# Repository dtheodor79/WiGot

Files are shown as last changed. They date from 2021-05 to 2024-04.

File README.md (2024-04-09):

# WiGot in a nutshell
WiGot is a quick effort for getting rid of all cables coming out from a Gotek drive installed in an Amiga. 
## Benefits
* No cables coming out of your Amiga
* Convenient image selection with rotary switch and OLED screen
 
 # Concept 
Up to know, most efforts focus on providing control panels with OLED screens, buttons / rotary switches, that are wired to the Gotek drive installed inside the Amiga. WiGot is a quick (and dirty) effort for getting rid of all cables coming out from a Gotek drive installed in an Amiga. It is based on connecting a small microcontoller with wireless connectivity capabilities inside the Gotek drive that emulates image selection from a rotary switch. An external wireless controller with OLED screen and a rotary switch, transmits user rotations to the internal microcontroller, which relays them to the Gotek processor.  
 
 # Prototype
 The current prototype is based on a SFRC9220 Gotek drive and two WeMos D1 EPS32 modules; the first one (A) is mounted inside a Gotek drive with HXC firmware, and the second one (B) allows users to select disk images. Communication works as follows: whenever the user rotates the switch, B informs A (including direction). A then simply uses the original Gotek rotary pins (that are already available) to emulate a full rotary (i.e. no grey encoding up to now). All data transfers are done using the [ESP Now](https://docs.espressif.com/projects/esp-idf/en/latest/esp32/api-reference/network/esp_now.html) wireless protocol.
 
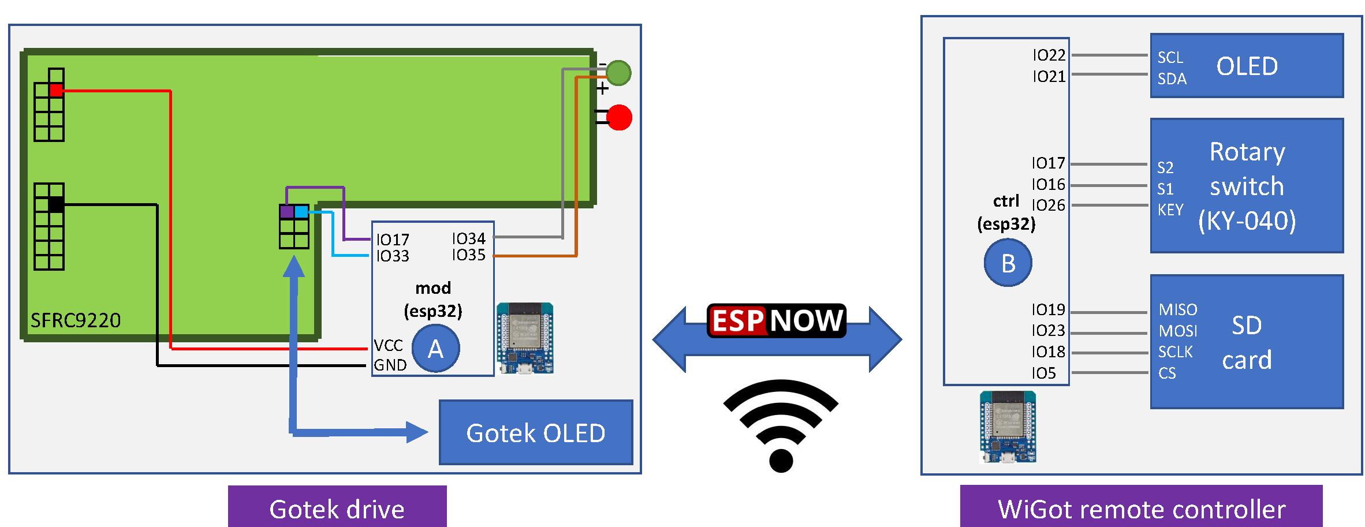
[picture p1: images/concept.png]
Concept


The image above illustates the WiGot concept, based on the two aforementioned WeMos D1 ESP32 modules, namely A and B. 

The left part shows how to connect A with the Gotek drive: 

* IO pins 17 and 33 are used to send fake rotary signals to the Gotek processor. 
* IO pins 34 and 35 are used to analog-read the voltage between the green led (L4 in the schematic), in order to identify whether the floopy is busy.
* VCC and GND pins are connected to the Gotek headers shown with red and black boxes.

The right parts shows how to build B:
* IO pins 22 and 21 are used for the I2C protocol required by the OLED.
* IO pins 17, 16 and 26 are connected to the S2, S1 and KEY pins respectevily of the KY-040 rotary switch.
* IO pins 19, 23, 18 and 5 are used for the SPI protocol required by the SD Card.

# How to use it
## First-time use
After you connect A to the Gotek drive as shown above, follow these steps:
### Create and save the data file
* Create a data.cfg file and edit it as follows:
    * the first line must contain the MAC address of A, seperated by commas. [Here](https://randomnerdtutorials.com/get-change-esp32-esp8266-mac-address-arduino/) you can see how to read the ESP MAC address. Example for MAC address B4:E6:2D:8F:D8:E1 in the data file:
        * B4,E6,2D,8F,D8,E1 
    * each subsequent line must contain a single image's data in the form of &lt;name&gt;,&lt;disk&gt;,&lt;total disks&gt;. Example with HXC firmware and Desert Strike images: 
        * HXCFECFGV1.0,1,1
        * Desert Strike,1,3
        * Desert Strike,2,3
        * Desert Strike,3,3
* Save the data file into your FAT32 formatted SD card.
* Plug the SD card into the slot of the controller module (B).
* An example of my data.cfg file can be found here.
### Power up
Now that you have created your data.cfg file and saved it in the SD card, follow these steps:
* Power up your Amiga, A will wait for B.
* Plug B to power, and check the OLED screen; it will take a while to establish connection with A and then ask you to set the current image.
* Rotate the switch until the image number matches the one shown in the Gotek OLED screen. When done, press the rotary switch once to sync the controller with the image selected in the Gotek drive.
* That's it! From now can use the rotary switch to select images.
## Regular use
Always power on first the Amiga and then directly the wireless controller B. Wait for a moment to establish connection and then start selecting images. In case you add / remove images, you need to update the data.cfg file as well, using the instructions above.

# FAQ - Troubleshoot
* Image number does not match the one shown in the Gotek drive OLED screen
  * If, for any reason, this happens, simply press the rotary switch to set again the currently selected image from the Gotek drive. Note that A and B should be already connected before syncing the image.
* Cannot establish connection between A and B
  * Make sure that the MAC address is correct and properly saved (each number separated by commas) in the first line of the data.cfg file.
* The rotary switch does not work properly
  * The WiGot current implementation assumes the following S1 and S2 (of the KY-040) states:
    * Single clockwise rotation (increases selected image by 1): 10 → 00 → 01 → 11 → 10
    * Single counter-clockwise rotation (decreases selected image by 1): 00 → 10 → 11 → 01 → 00  
 
# WiGot images

## Mod (A)

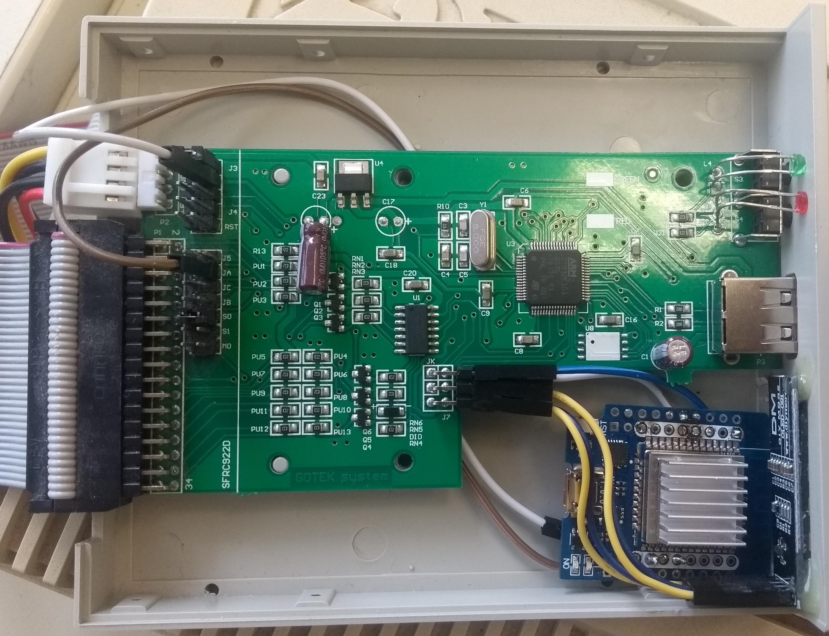
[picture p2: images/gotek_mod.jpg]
Gotek mod


## Wireless controller (B)

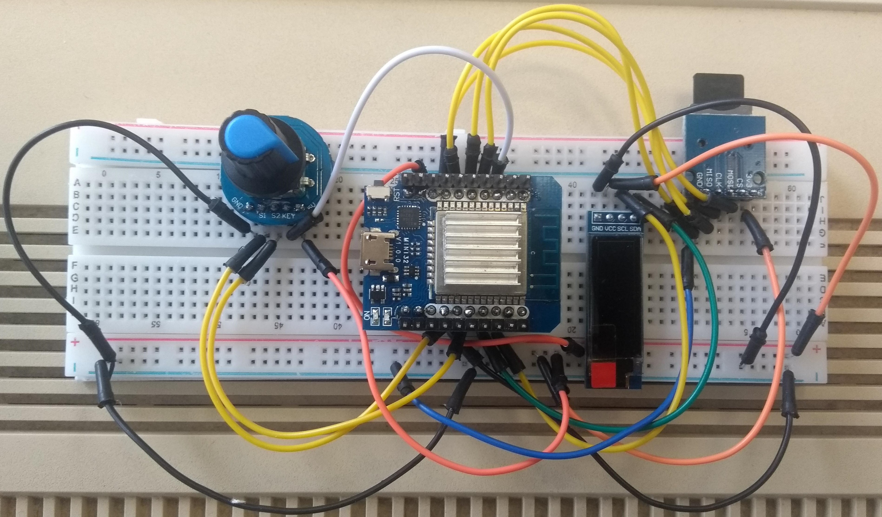
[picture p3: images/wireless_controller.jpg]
Wireless controller


Here you can find a clumsy PCB made with KiCAD for the wireless controller.

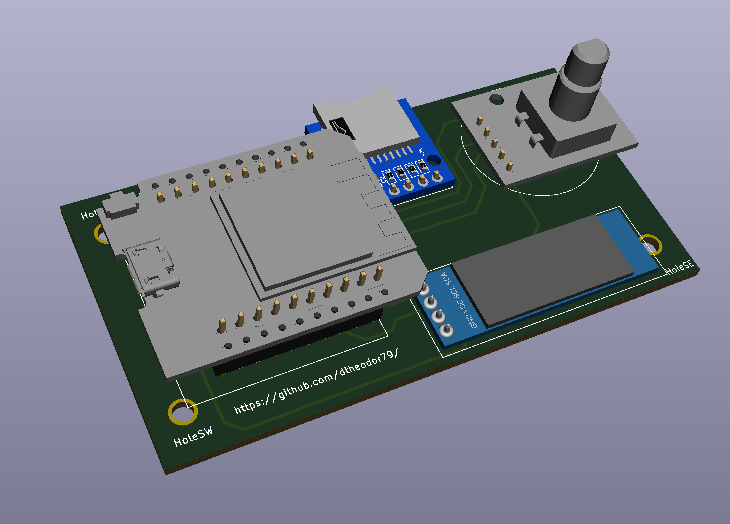
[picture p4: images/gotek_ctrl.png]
Model


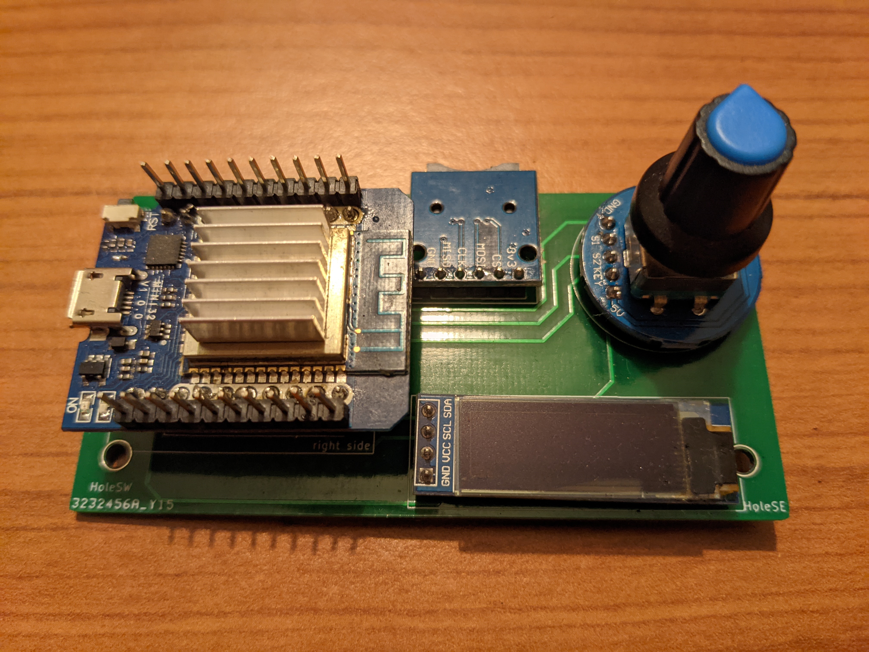
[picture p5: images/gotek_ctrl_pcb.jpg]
Controller_Pcb


Hope you find it useful!! :sunglasses:

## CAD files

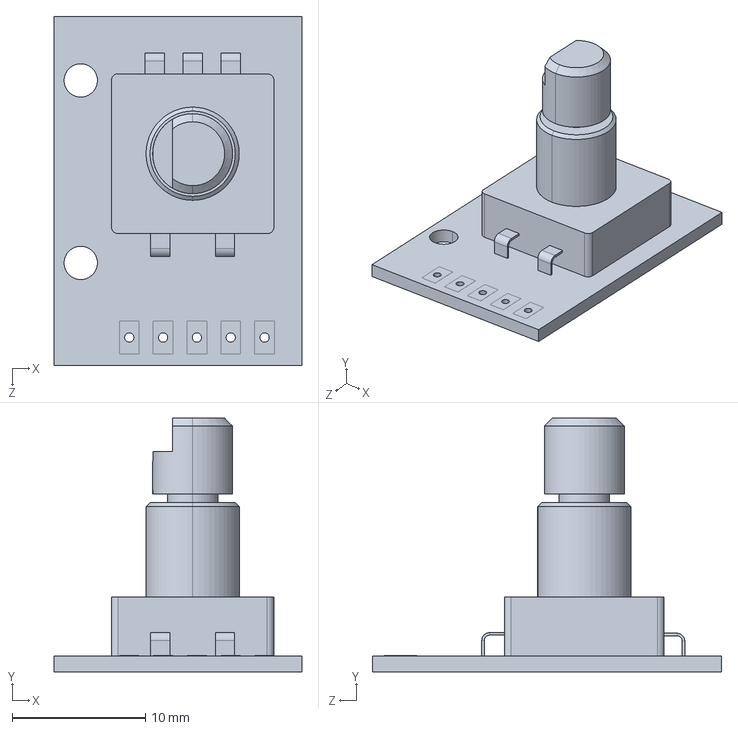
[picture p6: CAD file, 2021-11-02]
gotek_ctrl/pcb/3d models/Encoder KY-040.STEP
18.6 x 19.1 x 26.2 mm

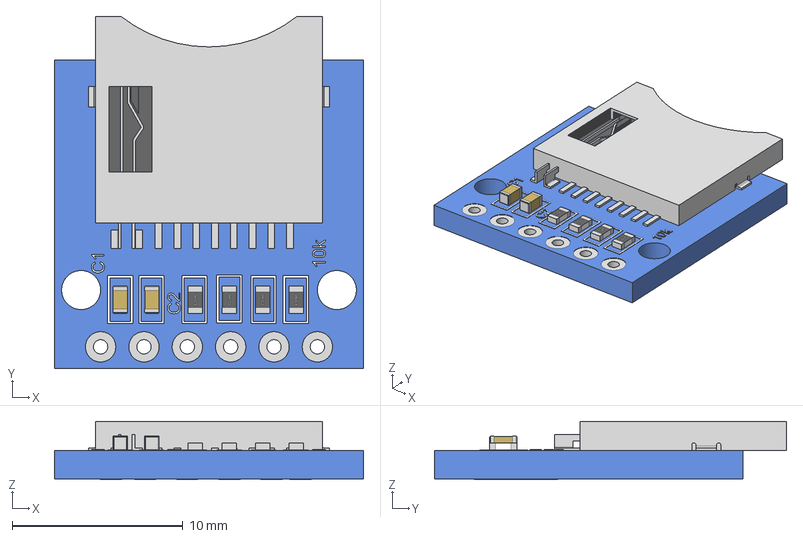
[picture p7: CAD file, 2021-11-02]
gotek_ctrl/pcb/3d models/MicroSD Card Module - 1.stp
18.1 x 20.6 x 3.40 mm
Micro SD Module - 1
MicroSD
0603 Capacitor x 2
0603 Resistor x 4

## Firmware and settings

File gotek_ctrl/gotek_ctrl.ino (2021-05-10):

#include <HardwareSerial.h>
#include <Wire.h>
#include <Adafruit_SSD1306.h>
#include <esp_now.h>
#include <WiFi.h>
#include "SD.h"
#include "SPI.h"
#include "FS.h"
#include <EEPROM.h>

#define SERIAL_UART_BAUD   57600 
#define LED_PIN       GPIO_NUM_2 
#define I2C_SDA       GPIO_NUM_21
#define I2C_SCL       GPIO_NUM_22
#define KY040_S2      GPIO_NUM_17
#define KY040_S1      GPIO_NUM_16
#define KY040_BUTTON  GPIO_NUM_26
#define INC10_BUTTON  GPIO_NUM_35  //TODO
#define DEC10_BUTTON  GPIO_NUM_33  //TODO
#define SCREEN_WIDTH 128 // OLED display width, in pixels
#define SCREEN_HEIGHT 32 // OLED display height, in pixels    
#define DISPLAY_I2C_ADDRESS 0x3C 

#define ROTARY_ENC_OUT_A  GPIO_NUM_19
#define ROTARY_ENC_OUT_B  GPIO_NUM_18

#define SD_MISO     GPIO_NUM_19
#define SD_MOSI     GPIO_NUM_23
#define SD_SCLK     GPIO_NUM_18
#define SD_CS       GPIO_NUM_5

#define OLED_TIMEOUT_MSEC 21000 
#define RX_DATA_START -9    
#define OLED_STATUS_REQUEST -6
#define OLED_STATUS_UNKNOWN -8
#define OLED_ON -7    
#define OLED_OFF -5
#define CONNECTION_TEST -2
#define ROTARY_DELAY_USEC 100000
#define ROTARY_OUTPUTS_DELAY 10
#define MIN_BUTTON_PRESSES_INTERVAL_MSEC 300
#define SWITCH_ROTATION_CCW -3
#define SWITCH_ROTATION_CW -4
#define MOD_PROBE_SUCCESS 0
#define MOD_PROBE_UNKNOWN -1
#define MOD_PROBE_FAIL 1
#define IMAGE_DATA_NUM 1024

uint32_t rotatorPressedTimestamp = 0;

typedef struct {
  char imageName[64];
  char currentDiskNum;  
  char totalDisksNum;  
} imageEntryData;

imageEntryData imageData[IMAGE_DATA_NUM];

bool aState = LOW, bState = LOW, settingGotekImage = false, dataFileFound = false, initProcessSuccess = false;
int8_t counter = 0, rotatorPressedCounter = 0, modProbeResult = MOD_PROBE_UNKNOWN;
bool oledAvailable = false, clearOledDisplay = false;

const int imageSettingIdx_eepromAdress = 0;
Adafruit_SSD1306 display(SCREEN_WIDTH, SCREEN_HEIGHT, &Wire, -1);
static uint8_t prevNextCode = 0;
static uint16_t store = 0;
static int16_t imageSettingIdx = -1, totalAvailableImages = 0, initOledStatus = OLED_STATUS_UNKNOWN;
uint32_t selectionSleepTimeMsec = OLED_TIMEOUT_MSEC;

//gotek_ctrl mac is CC:50:E3:B5:9E:38
//gotek_mod mac is CC:50:E3:B5:A1:1C
uint8_t gotekCtrlAddress[6];
//uint8_t gotekModAddress[] = {0xCC, 0x50, 0xE3, 0xB5, 0xA1, 0x1C};
uint8_t gotekModAddress[6]; //read from the SD card
portMUX_TYPE mux = portMUX_INITIALIZER_UNLOCKED;

void saveInt16ToEEPROM (int eepromAddress,int16_t value) {  
  EEPROM.put(eepromAddress, value);    
  EEPROM.commit();
}

int16_t loadInt16FromEEPROM(int eepromAddress) {
  int16_t readData;
  EEPROM.get(eepromAddress, readData);
  return readData;
}

void clearEEPROM() {
  Serial.print("clear EEPROM ");
  for (int i = 0; i < 512; i++) {
    EEPROM.write(i, -1);
  }
  EEPROM.commit();
  delay(500);
  Serial.println("done!");
}

//callback function that will be executed when data is received
void OnDataRecv(const uint8_t * mac, const uint8_t *incomingData, int len) {  
  int16_t dataReceived = 0;
  
  memcpy(&dataReceived, incomingData, sizeof(int16_t));
  Serial.print("Bytes received: ");
  Serial.println(len);  
  Serial.println("dataReceived = " + String(dataReceived)); 
  if (dataReceived >= 0) {
    imageSettingIdx = dataReceived;
    Serial.println("imageSettingIdx = " + String(imageSettingIdx)); 
    saveInt16ToEEPROM(imageSettingIdx_eepromAdress,imageSettingIdx);   
  }  
  else {
    if (dataReceived == (int16_t)OLED_OFF) {
      clearOledDisplay = true;
      initOledStatus = (int16_t)OLED_OFF;
    }
    else if (dataReceived == (int16_t)OLED_ON) {
      clearOledDisplay = false;
      initOledStatus = (int16_t)OLED_ON;
    }
  }  
}

// callback when data is sent
void OnDataSent(const uint8_t *mac_addr, esp_now_send_status_t status) {
  char macStr[18];
  Serial.print("Packet to: ");
  // Copies the sender mac address to a string
  snprintf(macStr, sizeof(macStr), "%02x:%02x:%02x:%02x:%02x:%02x",mac_addr[0], mac_addr[1], mac_addr[2], mac_addr[3], mac_addr[4], mac_addr[5]);
  Serial.print(macStr);
  Serial.print(" send status:\t");
  Serial.println(status == ESP_NOW_SEND_SUCCESS ? "Delivery Success" : "Delivery Fail");
  (status == ESP_NOW_SEND_SUCCESS) ? modProbeResult = MOD_PROBE_SUCCESS : modProbeResult = MOD_PROBE_FAIL;  
}

void rotatorPressedRoutine() {
  rotatorPressedCounter++;
  rotatorPressedTimestamp = millis();
  Serial.println("rotatorPressedRoutine, rotatorPressedCounter = " + String(rotatorPressedCounter) + ", settingGotekImage = " + String(settingGotekImage));  
  if (settingGotekImage) {
    if (imageSettingIdx >= 0) {
      settingGotekImage = false;
      sendDataToMod(imageSettingIdx);    
      writeToDisplay("Image set!");    
      delay(1000);
      showImageDataToDisplay();
    }
  }
  else {    
    setGotekImage();  
  }  
}

// A vald CW or  CCW move returns 1, invalid returns 0.
//credits for the debouncing function here: https://www.best-microcontroller-projects.com/rotary-encoder.html
int8_t readRotary() {
  static int8_t rotEncTable[] = {0,1,1,0,1,0,0,1,1,0,0,1,0,1,1,0};

  prevNextCode <<= 2;
  if (digitalRead(KY040_S1)) prevNextCode |= 0x02;
  if (digitalRead(KY040_S2)) prevNextCode |= 0x01;
  prevNextCode &= 0x0f;

  // If valid then store as 16 bit data.
  if  (rotEncTable[prevNextCode] ) {
    store <<= 4;
    store |= prevNextCode;      
    if ((store&0xff)==0x2b) return -1;
    if ((store&0xff)==0x17) return 1;
  }
  return 0;
}

void sendDataToMod(int16_t dataToSend) {
  esp_err_t result = esp_now_send(0, (uint8_t *) &dataToSend, sizeof(int16_t));  
}

void detectRotation() {  
  int8_t val;  bool cw = false;   

  if (val=readRotary()) {    
    cw = (val == 1);

    if (settingGotekImage) {
      imageSettingIdx +=val;      
      if (imageSettingIdx < 0) {
        imageSettingIdx = totalAvailableImages-1;  
      }
      if (imageSettingIdx > totalAvailableImages-1) {
        imageSettingIdx = 0; 
      }
      Serial.println("detectRotation , imageSettingIdx = " + String(imageSettingIdx));
      saveInt16ToEEPROM(imageSettingIdx_eepromAdress,imageSettingIdx);
    }
    setRotaryEncOutputsGotekStates(cw); 
  }  
}

void setRotaryEncOutputA(bool newState) {
  digitalWrite(ROTARY_ENC_OUT_A, newState);
  aState = newState;
}

void setRotaryEncOutputB(bool newState) {
  digitalWrite(ROTARY_ENC_OUT_B, newState);
  bState = newState;
}


void setRotaryEncOutputsGotekStates(bool cw) {
  Serial.println("setRotaryEncOutputsGotekStates, cw = " + String(cw));  
  if (cw) {
    //CW: 10 > 00 > 01 > 11 > 10
    setRotaryEncOutputA(HIGH); setRotaryEncOutputB(LOW);
    Serial.print(String(aState) + String(bState) + " -> ");     
    delay(ROTARY_OUTPUTS_DELAY); 
    setRotaryEncOutputA(LOW); setRotaryEncOutputB(LOW);
    Serial.print(String(aState) + String(bState) + " -> ");  
    delay(ROTARY_OUTPUTS_DELAY);
    setRotaryEncOutputA(LOW); setRotaryEncOutputB(HIGH);
    Serial.print(String(aState) + String(bState) + " -> ");    
    delay(ROTARY_OUTPUTS_DELAY);
    setRotaryEncOutputA(HIGH); setRotaryEncOutputB(HIGH);
    Serial.print(String(aState) + String(bState) + " -> ");   
    delay(ROTARY_OUTPUTS_DELAY);
    setRotaryEncOutputA(HIGH); setRotaryEncOutputB(LOW);
    Serial.println(String(aState) + String(bState));      
    delay(ROTARY_OUTPUTS_DELAY);
  }
  else {
    //CCW: 00 > 10 > 11 > 01 > 00
    setRotaryEncOutputA(LOW); setRotaryEncOutputB(LOW);
    Serial.print(String(aState) + String(bState) + " -> ");  
    delay(ROTARY_OUTPUTS_DELAY); 
    setRotaryEncOutputA(HIGH); setRotaryEncOutputB(LOW);
    Serial.print(String(aState) + String(bState) + " -> ");
    delay(ROTARY_OUTPUTS_DELAY);
    setRotaryEncOutputA(HIGH); setRotaryEncOutputB(HIGH);
    Serial.print(String(aState) + String(bState) + " -> ");
    delay(ROTARY_OUTPUTS_DELAY);
    setRotaryEncOutputA(LOW); setRotaryEncOutputB(HIGH);
    Serial.print(String(aState) + String(bState) + " -> ");
    delay(ROTARY_OUTPUTS_DELAY);
    setRotaryEncOutputA(LOW); setRotaryEncOutputB(LOW);
    Serial.println(String(aState) + String(bState));      
    delay(ROTARY_OUTPUTS_DELAY);
  }  

  showImageDataToDisplay();
  
  if (!settingGotekImage) {    
    int16_t cwRotation = (cw == true) ? SWITCH_ROTATION_CW : SWITCH_ROTATION_CCW;
    //esp_err_t result = esp_now_send(0, (uint8_t *) &cwRotation, sizeof(uint8_t));  
    sendDataToMod(cwRotation);
  }
}

void showImageDataToDisplay() {
  Serial.println("imageSettingIdx = " + String(imageSettingIdx));
  if ((imageSettingIdx >=0) && (imageSettingIdx < IMAGE_DATA_NUM)) {
    String textToDisplay = String("Image ") + String(imageSettingIdx) + String( " / ") + String(totalAvailableImages-1) + String("\n\n") + String(imageData[imageSettingIdx].imageName) + String("\nDisk ") + String(imageData[imageSettingIdx].currentDiskNum) + String(" / ") + String(imageData[imageSettingIdx].totalDisksNum);
    writeToDisplay(textToDisplay);  
  }
  else {  //ask the user to set the currently selected image in Gotek
    setGotekImage();
  }
}

void setGotekImage(){
  settingGotekImage = true;    
  writeToDisplay("Set active image.");
}

void writeToDisplay(String text) {
  if (oledAvailable) {    
    Serial.println("writeToDisplay: text = " + text);      
    display.clearDisplay();
    display.setCursor(0, 0);  
    display.println(text);
    display.display(); 

    digitalWrite(LED_PIN,text.length() > 0);
  }  
}

void readDataFile(File imagesFile) {
  Serial.println("readDataFile...");      
  char buffer[64]; 
  int i=0;
  while (imagesFile.available()) {
    int l = imagesFile.readBytesUntil('\n', buffer, sizeof(buffer));
    buffer[l] = 0;

    char* imageMetaData = strtok(buffer, ","); 
    if (i==0) {  //contains the mod MAC address      
      sscanf(imageMetaData,"%02x",&gotekModAddress[0]);                       
      imageMetaData = strtok(NULL, ","); sscanf(imageMetaData,"%02x",&gotekModAddress[1]);  
      imageMetaData = strtok(NULL, ","); sscanf(imageMetaData,"%02x",&gotekModAddress[2]);  
      imageMetaData = strtok(NULL, ","); sscanf(imageMetaData,"%02x",&gotekModAddress[3]);  
      imageMetaData = strtok(NULL, ","); sscanf(imageMetaData,"%02x",&gotekModAddress[4]);  
      imageMetaData = strtok(NULL, ","); sscanf(imageMetaData,"%02x",&gotekModAddress[5]);  
      
      Serial.print("mod MAC address: ");
      for (int j=0;j<5;j++) {
        Serial.print(String(gotekModAddress[j],HEX) + ":");
      }
      Serial.println(String(gotekModAddress[5],HEX));
    }
    else {
      strcpy(&(imageData[i-1].imageName[0]),imageMetaData);
      imageMetaData = strtok(NULL, ","); 
      strcpy(&(imageData[i-1].currentDiskNum),imageMetaData);
      imageMetaData = strtok(NULL, ","); 
      strcpy(&(imageData[i-1].totalDisksNum),imageMetaData);
    }      
    i++;     
  }
  totalAvailableImages = i-1;
  Serial.println("totalAvailableImages = " + String(totalAvailableImages));
  printImageNames(); 
}

void printImageNames() {  
  for (int i=0;i<totalAvailableImages;i++) {    
    Serial.println("imageName: " + String(imageData[i].imageName) + ", currentDiskNum: " + String(imageData[i].currentDiskNum) + ", totalDisksNum: " + String(imageData[i].totalDisksNum));
  }
}


bool initializeOLED() {
  byte errorResult;
  Wire.beginTransmission(DISPLAY_I2C_ADDRESS);
  errorResult = Wire.endTransmission(); 

  if (errorResult == 0) {
    if (!display.begin(SSD1306_SWITCHCAPVCC, DISPLAY_I2C_ADDRESS)) { // Address 0x3C for 128x32
      Serial.println("SSD1306 allocation failed"); 
      return false;   
    }
    else {
      Serial.println("SSD1306 allocation successful!");    
      // Clear the buffer
      display.clearDisplay();
      display.setTextSize(1); // Draw 2X-scale text
      display.setTextColor(SSD1306_WHITE);    
    }
    return true;
  }

  Serial.println("SSD1306 not available!");    
  return false;
}

void checkIfRotatorPressed() {
  if (digitalRead(KY040_BUTTON) == LOW) {
    if (rotatorPressedTimestamp == 0) {
      rotatorPressedRoutine();    
    }
    else {    
      if (millis() - rotatorPressedTimestamp > MIN_BUTTON_PRESSES_INTERVAL_MSEC) {
        rotatorPressedRoutine();
      }
    }
  }  
}

bool sendInitDataToMod() {
  uint8_t maxTries = 20, progress = 0, progressStep = 12;
  
  Serial.println("sendInitDataToMod..");

  WiFi.macAddress(gotekCtrlAddress);
  for (int i=0;i<6;i++) {
    Serial.println("gotekCtrlAddress[" + String(i) + "] = " + String(gotekCtrlAddress[i],HEX));    
  } 
  
  do {
    delay(1000);
    sendDataToMod((int16_t)RX_DATA_START);
    if (modProbeResult != MOD_PROBE_SUCCESS) {
      maxTries--;      
    }    
  }
  while ((modProbeResult != MOD_PROBE_SUCCESS) && (maxTries >= 0));
  progress = progress + progressStep;
  writeToDisplay("Connecting to mod...\n" + String(progress) + "%");

  for (int i=0;i<6;i++) {
    do {
    delay(1000);
      sendDataToMod((int16_t)gotekCtrlAddress[i]);  
      if (modProbeResult != MOD_PROBE_SUCCESS) {
        maxTries--;      
      } 
    }
    while ((modProbeResult != MOD_PROBE_SUCCESS) && (maxTries >= 0));
    progress = progress + progressStep;
    writeToDisplay("Connecting to mod...\n" + String(progress) + "%");
  }

  do {
    delay(1000);
    sendDataToMod((int16_t)totalAvailableImages);
    if (modProbeResult != MOD_PROBE_SUCCESS) {
      maxTries--;      
    }    
  }
  while ((modProbeResult != MOD_PROBE_SUCCESS) && (maxTries >= 0));

  Serial.println("sendInitDataToMod, maxTries = " + String(maxTries));
  if (maxTries >=0) {
    writeToDisplay("Connecting to mod...\ndone!");
    return true;
  }

  writeToDisplay("Connecting to mod...\nerror :(");
  return false;
   
}


void setup() {
  int i=0;
  Serial.begin(SERIAL_UART_BAUD);
  delay(1000);  
  Serial.println("Starting gotek ctrl..."); 
  Wire.begin();  
  delay(1000);  
  WiFi.mode(WIFI_STA);  
  delay(1000);  
  Serial.println("MAC address: " + WiFi.macAddress());  

  EEPROM.begin(512);  
  //clearEEPROM(); 

  imageSettingIdx = loadInt16FromEEPROM(imageSettingIdx_eepromAdress); 
  Serial.println("imageSettingIdx = " + String(imageSettingIdx));

  pinMode(KY040_S2, INPUT);  
  pinMode(KY040_S2, INPUT_PULLUP);  
  pinMode(KY040_S1, INPUT);  
  pinMode(KY040_S1, INPUT_PULLUP);
  pinMode(KY040_BUTTON, INPUT); 

  pinMode(ROTARY_ENC_OUT_A, OUTPUT);
  setRotaryEncOutputA(LOW);
  pinMode(ROTARY_ENC_OUT_B, OUTPUT);
  setRotaryEncOutputB(LOW);
  pinMode(LED_PIN, OUTPUT);

  oledAvailable = initializeOLED();  
  writeToDisplay("Initializing...");  
  
  if (!SD.begin(SD_CS)){
    Serial.println("Card Mount Failed.");
    writeToDisplay("Card Mount Failed.");    
    return;
  }
  uint8_t cardType = SD.cardType();

  if (cardType == CARD_NONE){
    Serial.println("No SD card attached.");
    writeToDisplay("No SD card attached.");
    return;
  }

  Serial.print("SD Card Type: ");
  if (cardType == CARD_MMC){
    Serial.println("MMC");
  } 
  else if (cardType == CARD_SD){
    Serial.println("SDSC");
  } 
  else if (cardType == CARD_SDHC){
    Serial.println("SDHC");
  } 
  else {
    Serial.println("UNKNOWN");
  }

  uint64_t cardSize = SD.cardSize() / (1024 * 1024);
  Serial.printf("SD Card Size: %lluMB\n", cardSize);
  
  
  File imagesFile = SD.open("/data.cfg"); 
  if (!imagesFile){
    Serial.println("There was an error opening imagesFile");  
    writeToDisplay("\"data.cfg\" file not\nfound!"); 
    dataFileFound = false; 
    return;
  }
  else {
    Serial.println("imagesFile size = " + String(imagesFile.size()) + " bytes"); 
    dataFileFound = true;
    readDataFile(imagesFile);   
  }
  imagesFile.close();

  if (esp_now_init() != ESP_OK) {
    Serial.println("Error initializing ESP-NOW");
    writeToDisplay("Error connecting with Gotek.");
    return;
  }
  else {
    Serial.println("ESP-NOW initialized!");
  }
  
  esp_now_register_send_cb(OnDataSent);
  esp_now_register_recv_cb(OnDataRecv);
  // register gotekMod
  esp_now_peer_info_t gotekModInfo;
  gotekModInfo.channel = 0;  
  gotekModInfo.encrypt = false;
  // register first peer  
  memcpy(gotekModInfo.peer_addr, gotekModAddress, 6);
  if (esp_now_add_peer(&gotekModInfo) != ESP_OK){
    Serial.println("Failed to add peer");
    return;
  }
  else {
    Serial.println("Successfully added Gotek mod!");
    writeToDisplay("Connecting to mod...");
  }

  do {
    sendDataToMod((int16_t)CONNECTION_TEST);
    Serial.println("modProbeResult = " + String(modProbeResult));
    delay(1000);  
  }
  while (modProbeResult != MOD_PROBE_SUCCESS); 

  if (!dataFileFound) {
    writeToDisplay("\"data.cfg\" file not\nfound!"); 
    delay(1000);
  }

  //send initial data to mod
  initProcessSuccess = sendInitDataToMod();
  
  
}

void loop() {
  static bool connectionSuccess = true; 
  static int16_t prevImageSettingIdx = -1; 

  if (!initProcessSuccess) {
    return;
  }

  if (modProbeResult == MOD_PROBE_SUCCESS) {
    if (!connectionSuccess) {
      connectionSuccess = true;    
      showImageDataToDisplay();             
    }
    detectRotation();
    checkIfRotatorPressed(); 
    if (prevImageSettingIdx != imageSettingIdx) {
      showImageDataToDisplay(); 
      prevImageSettingIdx = imageSettingIdx;
    }      

    if (clearOledDisplay) {
      writeToDisplay("");
      clearOledDisplay = false;
    }
    
  }
  else {
    connectionSuccess = false;
    writeToDisplay("Not connected to mod!");
    sendDataToMod((int16_t)CONNECTION_TEST);
    delay(1000);
  }  
}

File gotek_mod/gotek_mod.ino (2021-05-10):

#include <HardwareSerial.h>
#include "WiFi.h"
#include <esp_now.h>
#include "driver/rtc_io.h"
#include <EEPROM.h>

#define SERIAL_UART_BAUD   57600  

#define RX_DATA_START -9    
#define OLED_STATUS_REQUEST -6
#define OLED_STATUS_UNKNOWN -8
#define OLED_ON -7    
#define OLED_OFF -5
#define SWITCH_ROTATION_CCW -3
#define SWITCH_ROTATION_CW -4
#define CONNECTION_TEST -2
#define CTRL_PROBE_SUCCESS 0
#define CTRL_PROBE_UNKNOWN -1
#define CTRL_PROBE_FAIL 1

#define LED_PIN GPIO_NUM_2
#define ROTARY_ENC_OUT_A  GPIO_NUM_33 
#define ROTARY_ENC_OUT_B  GPIO_NUM_17 
#define FLOPPY_LED_PLUS   GPIO_NUM_35
#define FLOPPY_LED_MINUS    GPIO_NUM_34
#define FLOPPY_READ_THRESHOLD 4000      
#define OLED_TIMEOUT_MSEC 21000     
#define IMAGE_DATA_NUM 1024

#define ROTARY_OUTPUTS_DELAY 10
#define TIMEOUT_TIMER_ID 0

//gotek_ctrl mac is CC:50:E3:B5:9E:38
//gotek_mod mac is CC:50:E3:B5:A1:1C
//uint8_t gotekCtrlAddress[] = {0xCC, 0x50, 0xE3, 0xB5, 0x9E, 0x38};
uint8_t gotekCtrlAddress[6];
hw_timer_t * timeOutTimer = NULL;
portMUX_TYPE timerMux = portMUX_INITIALIZER_UNLOCKED;
bool aState = LOW, bState = LOW, oledIsOn = true, prevOledIsOn = false,  floppyBusy = false, receivingInitDataFromCtrl = false;
uint32_t oledTimeOutMsec = OLED_TIMEOUT_MSEC, countDownTimerMsec = OLED_TIMEOUT_MSEC;
int16_t imageIdx = -1, totalAvailableImages = 0;
int8_t ctrlProbeResult = CTRL_PROBE_UNKNOWN, macRxIdx = 0;
const int imageIdx_eepromAdress = 0;

void saveInt16ToEEPROM (int eepromAddress,int16_t value) {  
  EEPROM.put(eepromAddress, value);    
  EEPROM.commit();
}

int16_t loadInt16FromEEPROM(int eepromAddress) {
  int16_t readData;
  EEPROM.get(eepromAddress, readData);
  return readData;
}

void clearEEPROM() {
  Serial.print("clear EEPROM ");
  for (int i = 0; i < 512; i++) {
    EEPROM.write(i, -1);
  }
  EEPROM.commit();
  delay(500);
  Serial.println("done!");
}

// callback when data is sent
void OnDataSent(const uint8_t *mac_addr, esp_now_send_status_t status) {
  char macStr[18];
  Serial.print("Packet to: ");
  // Copies the sender mac address to a string
  snprintf(macStr, sizeof(macStr), "%02x:%02x:%02x:%02x:%02x:%02x",mac_addr[0], mac_addr[1], mac_addr[2], mac_addr[3], mac_addr[4], mac_addr[5]);
  Serial.print(macStr);
  Serial.print(" send status:\t");
  Serial.println(status == ESP_NOW_SEND_SUCCESS ? "Delivery Success" : "Delivery Fail");
  (status == ESP_NOW_SEND_SUCCESS) ? ctrlProbeResult = CTRL_PROBE_SUCCESS : ctrlProbeResult = CTRL_PROBE_FAIL;  
}

//callback function that will be executed when data is received
void OnDataRecv(const uint8_t * mac, const uint8_t *incomingData, int len) {
  int16_t dataReceived = SWITCH_ROTATION_CCW;
  memcpy(&dataReceived, incomingData, sizeof(int16_t));
  Serial.print("Bytes received: ");
  Serial.println(len);  

  if (receivingInitDataFromCtrl) {
    if ((macRxIdx >= 0) && (macRxIdx <=5)) {
      Serial.println("dataReceived = 0x" + String(dataReceived,HEX));
      gotekCtrlAddress[macRxIdx] = (uint8_t)dataReceived;
    }
    else if (macRxIdx == 6) {
      Serial.println("dataReceived = " + String(dataReceived));
      totalAvailableImages = dataReceived;
      receivingInitDataFromCtrl = false;       
    }    
    macRxIdx++;
  }
  else {      
    Serial.println("dataReceived = " + String(dataReceived));
    if (dataReceived != CONNECTION_TEST) { //ignore connection test message
      if (dataReceived < 0) {
        if (dataReceived == (int16_t)OLED_STATUS_REQUEST) {
          int16_t tmpOledStatus = (oledIsOn) ? OLED_ON : OLED_OFF;
          sendDataToCtrl(tmpOledStatus);
        }
        else if (dataReceived == (int16_t)RX_DATA_START) {
          receivingInitDataFromCtrl = true;
        }
        else {
          setRotaryEncOutputsGotekStates(dataReceived == SWITCH_ROTATION_CW);   
        }
      }
      else {
        imageIdx = dataReceived;
        Serial.println("imageIdx = " + String(imageIdx));
      }    
    }
  }
}

void sendDataToCtrl(int16_t dataToSend) {
  esp_err_t result = esp_now_send(0, (uint8_t *) &dataToSend, sizeof(int16_t));  
}

void IRAM_ATTR timerExpired() {
  portENTER_CRITICAL_ISR(&timerMux);  
  oledIsOn = false;
  portEXIT_CRITICAL_ISR(&timerMux); 
}

void stopTimeoutTimer() {
  Serial.println("stopTimeoutTimer..");  
  timerEnd(timeOutTimer);
  timeOutTimer = NULL;
}

void startTimeoutTimer() {    
  if (timeOutTimer != NULL) {
    stopTimeoutTimer();
  }
  Serial.println("startTimeoutTimer..");  
  timeOutTimer = timerBegin(TIMEOUT_TIMER_ID, 80, true);
  timerAttachInterrupt(timeOutTimer, &timerExpired, true);
  timerAlarmWrite(timeOutTimer, 1000 * OLED_TIMEOUT_MSEC, true);
  timerAlarmEnable(timeOutTimer);  
}

void setRotaryEncOutputA(bool newState) {
  digitalWrite(ROTARY_ENC_OUT_A, newState);
  aState = newState;
}

void setRotaryEncOutputB(bool newState) {
  digitalWrite(ROTARY_ENC_OUT_B, newState);
  bState = newState;
}

void setRotaryEncOutputsGotekStates(bool cw) {
  Serial.println("setRotaryEncOutputsGotekStates, cw = " + String(cw));  
  if (cw) {
    //CW: 10 > 00 > 01 > 11 > 10
    setRotaryEncOutputA(HIGH); setRotaryEncOutputB(LOW);
    Serial.print(String(aState) + String(bState) + " -> ");     
    delay(ROTARY_OUTPUTS_DELAY); 
    setRotaryEncOutputA(LOW); setRotaryEncOutputB(LOW);
    Serial.print(String(aState) + String(bState) + " -> ");  
    delay(ROTARY_OUTPUTS_DELAY);
    setRotaryEncOutputA(LOW); setRotaryEncOutputB(HIGH);
    Serial.print(String(aState) + String(bState) + " -> ");    
    delay(ROTARY_OUTPUTS_DELAY);
    setRotaryEncOutputA(HIGH); setRotaryEncOutputB(HIGH);
    Serial.print(String(aState) + String(bState) + " -> ");   
    delay(ROTARY_OUTPUTS_DELAY);
    setRotaryEncOutputA(HIGH); setRotaryEncOutputB(LOW);
    Serial.println(String(aState) + String(bState));      
    delay(ROTARY_OUTPUTS_DELAY);
  }
  else {
    //CCW: 00 > 10 > 11 > 01 > 00
    setRotaryEncOutputA(LOW); setRotaryEncOutputB(LOW);
    Serial.print(String(aState) + String(bState) + " -> ");  
    delay(ROTARY_OUTPUTS_DELAY); 
    setRotaryEncOutputA(HIGH); setRotaryEncOutputB(LOW);
    Serial.print(String(aState) + String(bState) + " -> ");
    delay(ROTARY_OUTPUTS_DELAY);
    setRotaryEncOutputA(HIGH); setRotaryEncOutputB(HIGH);
    Serial.print(String(aState) + String(bState) + " -> ");
    delay(ROTARY_OUTPUTS_DELAY);
    setRotaryEncOutputA(LOW); setRotaryEncOutputB(HIGH);
    Serial.print(String(aState) + String(bState) + " -> ");
    delay(ROTARY_OUTPUTS_DELAY);
    setRotaryEncOutputA(LOW); setRotaryEncOutputB(LOW);
    Serial.println(String(aState) + String(bState));      
    delay(ROTARY_OUTPUTS_DELAY);
  }  
  updateIndex(cw);
  oledIsOn = true;
  startTimeoutTimer();
}
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

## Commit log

2021-11-02 fixed 3d model
    [Encoder KY-040.STEP, MicroSD Card Module - 1.stp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]
2021-11-02 pcb rounded corners
    [gotek_ctrl.kicad_pcb]
